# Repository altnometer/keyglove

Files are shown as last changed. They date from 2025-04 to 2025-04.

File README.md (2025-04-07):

# keyglove

This repository contains:
- Fusion API scripts which generate 3D model parts that can be used to
  assemble an ergonomic computer keyboard.
- STL files for printing a prototype of the keyboard.
  - Please be aware that the prototype version does not matches the
    latest script settings. You will need to wait a couple of months
    for the first tagged version which will match the scripts
    settings. From that point, you will be able to adjust the scripts
    and print out parts for your own preferences.

You can get a free hobbyist/learner license from Autodesk and try out
these scripts in Fusion platform for 3D CAD (Computer-Aided
Design).

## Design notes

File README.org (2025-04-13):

* Projects name: Customizable KeyGlove keyboard

This repository can help you build a personalized keyboard that
matches your hand for a close to perfect fit.

1. Use the provided scripts ([[./fingers.py]] and [[./thumb.py]]) to adjust
   the
   - location,
     + in horizontal and
     + vertical dimensions,
   - incline and
   - rotation
   of the keys to match exactly your finger placement.
2. Combine the parts in CAD (computer aided design) program.
3. Print out.
4. Build.
5. Try out.
6. Repeat until satisfied.

#+caption: keyglove_ergonomic_keyboard
#+ATTR_ORG: :width 800px
#+attr_html: :width 150px
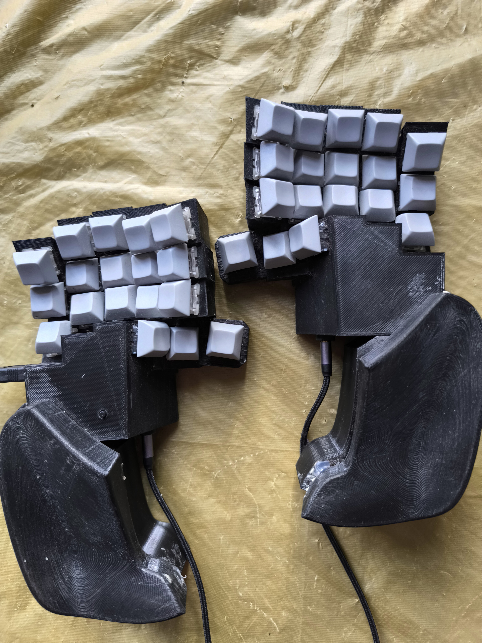
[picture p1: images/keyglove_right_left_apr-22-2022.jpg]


** [[Table of Contents]]

** [[Project Overview]]

** [[Features]]

** [[Parts List]]

** [[Build Process]]

** [[Wiring and Soldering]]

** [[QMK Firmware Setup]]

** [[Usage]]

** [[Customazation]]

** [[Contributing]]

** [[License]]

** [[Acknowledgments]]

* Project Overview

From play dough concept:
#+caption: keyglove_playdough_concept
#+ATTR_ORG: :width 800px
#+attr_html: :width 150px
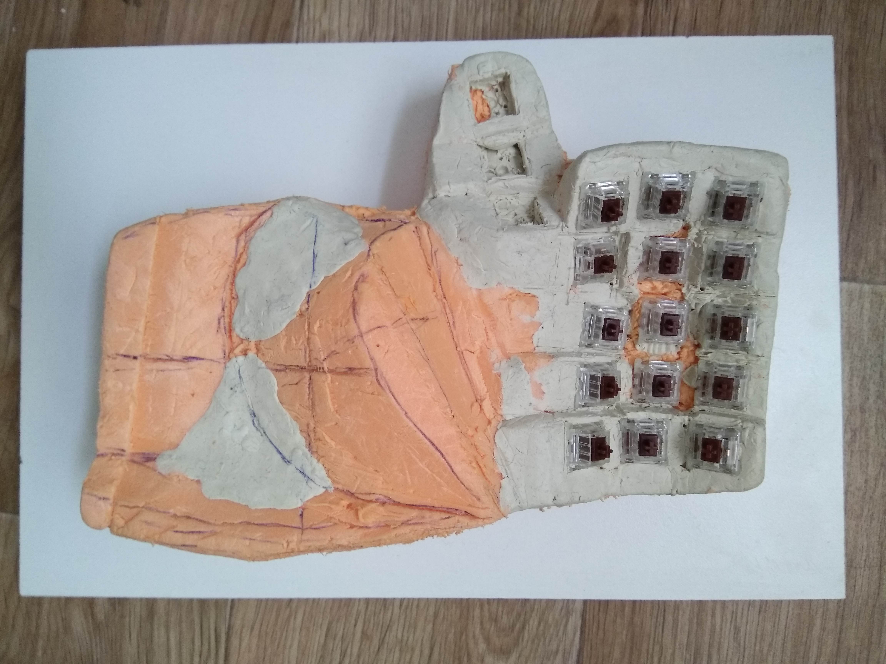
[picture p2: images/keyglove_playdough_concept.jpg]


Through countless trials:
#+caption: keyglove_3d_print_model
#+ATTR_ORG: :width 800px
#+attr_html: :width 150px
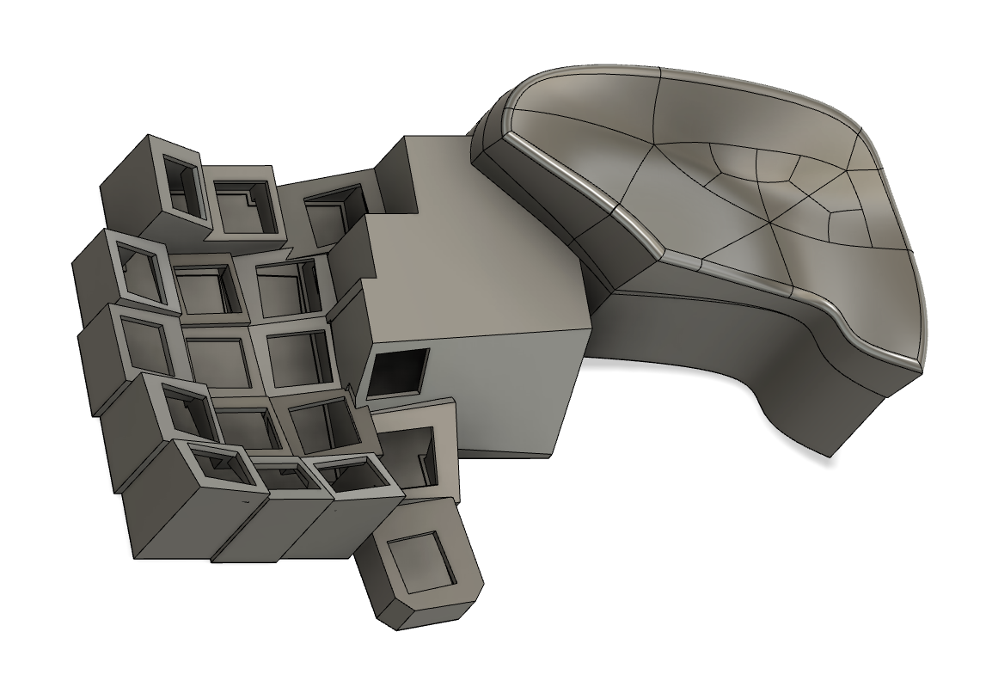
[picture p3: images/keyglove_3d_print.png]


Close to a perfect fit:
#+caption: keyglove_ergonomic_keyboard
#+ATTR_ORG: :width 800px
#+attr_html: :width 150px
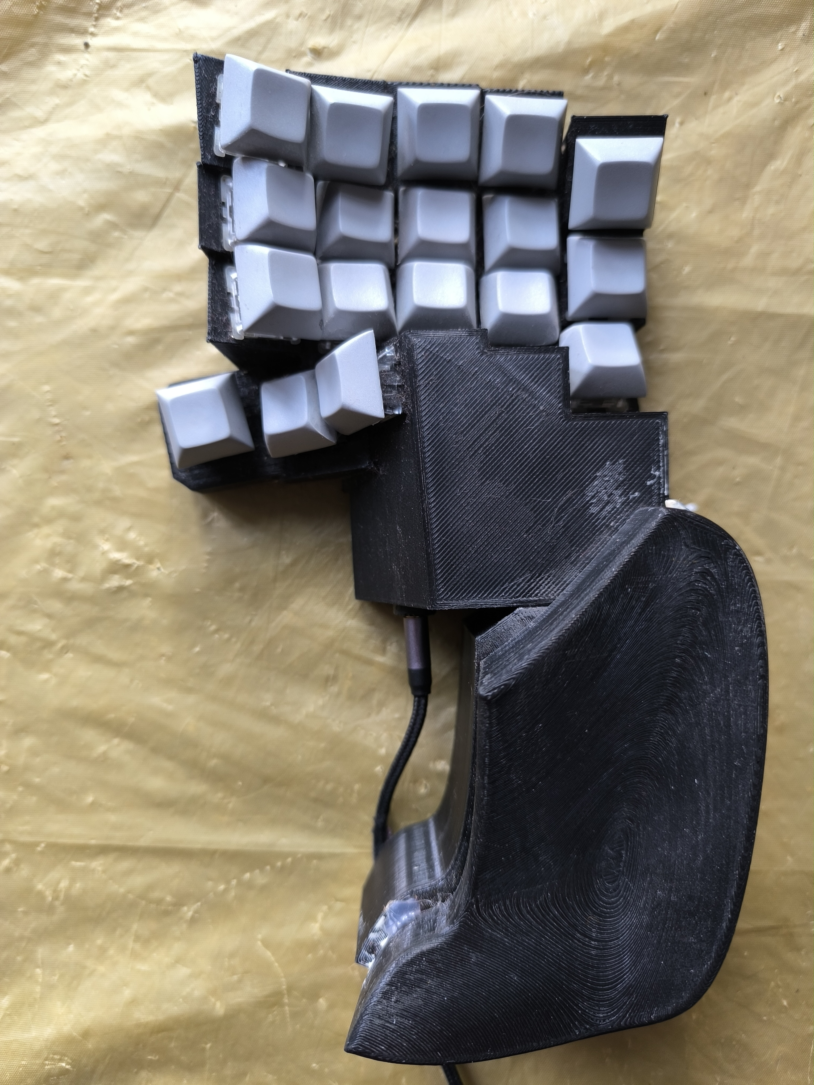
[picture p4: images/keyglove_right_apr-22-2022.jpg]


TODO:
A brief description of your keyboard:
- what makes it unique (e.g., ergonomic, wireless, THIRD-printed case).
- Target audience (e.g., writers, coders, gamers, etc).
- Tools required (soldering tools, THIRD printer, etc).

* Features

** Layout

1. The location, incline and rotation of every key is found through
   countless trials to match the optimal placement of fingers of my
   hand. No lifting of the palm is necessary to input the whole range
   of characters.
2. (TODO: link) The [[QMK Firmware Setup][QMK firmware]] is used
   - to enable the layout with all modifier keys (i.e., =Ctrl=, =Shift=
     and =Meta=) on the home row.
   - to enable activating the layout layers for
     + numbers and
     + symbols

** Switches

Your preferred switches, e.g.,
- Cherry MX Blue,
- Gateron Brown,
- etc

** Connectivity

USB

** Case Material

3D-printed,
Tried only:
- PEG type plastics for durability and strength

* Parts List

There are 36 keys in this keyboard. Hence, for things like
- key switches
- keycaps
- diods
- etc
You will need at least 36 pieces of each. Make sure you have some
spare ones as well.

** 3D-Printed Case

Start by printing the cases from provided STL files. If you wish to
adjust the key positions, use the scripts (TODO: link) to create
modified cases (for right and left hands).

** Microcontroller

Quantity: 2

** Key Switches

1. key switches, e.g.,  Gateron Browns, Plus a few spare ones
2. Different keys for finger keys (e.g., Gateron Brown) and thumb keys
   (used mainly for layer switching), e.g., Kailh Silver, linear, with
   shorter activation levels, with added key rings to minimize time,
   distance traveled for faster responses.

** Keycaps

DSA key caps. Please, be advise, you will need to grind off some of
the keycaps to fit them. Hence, make sure you have some spare keycaps.

 [[https://aliexpress.ru/item/32850729893.html?spm=a2g2w.orderdetail.0.0.12124aa6Vw1juY&sku_id=65628321594][AliExpress DSA keycaps]]

** Diodes

quality diodes.

** 4 pole 3.5mm trrs audio jack socket

Make sure it is of trrs type (not yrs).

For example:
[[./images/trrs_audio_jack_socket.jpg_220x220.webp]]

** other parts

TODO: make their own sections

4 pole 3.5mm trrs audio jack cable

USB type A (largest USB connectors for durability).
- socket
- cable

** soldering wire

* Build Process

** Prepare the Case

Print the case from the =3d_prints= directory. Ensure that surfaces for
the key switches are even and smooth. Sand and finish to your liking.

** Assemble Components

- Glue the switches section and hand rest section together.
- find the best location for the palm rest section (location for the right and left
  hands may differ).

Mount switches:
- ensure consistent orientation
Mount other components
- USB socket
- trrs socket
  + connect right and left hand parts
  + !!! Never disconnect right and left parts while the keyboard is
    powered.
- TODO: complete list

There is not specific holder for the micro controller.

** Solder Switches and Diodes

*** Wiring and Soldering

TODO: add images of wiring

Maybe (not likely) wiring schematic on or Fritzing diagram.

**** switches and diodes

**** 4 pole 3.5mm trrs audio jack socket

Insert, then solder.

!!! Pull up resistor (include resistor specs).

**** USB type A

Insert, then solder.

There is a rudimentary holder for the socket. You may need to cut the
place holder to size. Just use the soldering iron to melt it to size.
Glue for greater strength.

* QMK Firmware Setup

Please, see the [[https://github.com/altnometer/qmk_firmware][my QMK firmwaer repository]] for the configuration
examples.

In this repository, my settings for this keyboard are located in:
- =./qmk_firmware/keyboards/handwired/altnometer/= directory

** Example of BEAKL 10 layout

As an example, consider the settings for the BEAKL 10 layout located
in the file:
- =./qmk_firmware/keyboards/handwired/altnometer/keymaps/beakl/keymap.c=

Here is the relevant extract from the file:
#+begin_src C
// ./qmk_firmware/keyboards/handwired/altnometer/keymaps/beakl/keymap.c

// ...

/* _BEAKL (beakl10)
 * ,----------------------------------.             ,----------------------------------.
 * |  Q   |  H   |  O   |  U   |  X   |             |   G  |   D  |   N  |   M  |   V  |
 * |------+------+------+------+------+             +------+------+------+------+------|
 * |  Y   |  I   |  E   |  A   | .  # |             |   C  |   S  |   R  |   T  |   W  |
 * |------+------+------+------+------+             +------+------+------+------+------|
 * |  J   | /  ? | '  ` | ,  ! |  Z   |             |   B  |   P  |   L  |   F  |   K  |
 * `------+------+------+------+------+             +------+------+------+------+------'
 *               | Esc  | Spc  | BkSp |             |  Tab | Entr |  Esc |
 *               `--------------------'             `--------------------'
 *                   ^      ^      ^                    ^      ^      ^
 *                  I3     Symb   Nav                 Shft    Num    Shft
 */
 [_BEAKL] = LAYOUT(
  KC_Q   , KC_H   , KC_O   , KC_U   , KC_X   ,                   KC_G   , KC_D   , KC_N   , KC_M   , KC_V   ,
  KC_Y   , MALT_I , MSFT_E , MCTL_A , MY_DOT ,                   KC_C   , MCTL_S , MSFT_R , MALT_T , KC_W,
  KC_J   , KC_SLSH, MY_QUOT, MY_MINS, KC_Z   ,                   KC_B   , KC_P   , KC_L   , KC_F   , KC_K   ,
                    MGUI_BS, L_SYMSP, L_NAVES,                   L_FLRME, L_NUMEN, MY_ALTF
                    /* MGUI_BS, L_SYMSP, L_NAVES,                   L_FLRME, L_NUMEN, KC_TAB */
                    /* MGUI_BS, L_SYMSP, L_NAVES,                   L_FLRME, L_NUMEN, TH(0) */
),

// ...

#+end_src

** Firmware settings relevant to wiring

The settings specific to wiring this keyboard are located in:
- =./qmk_firmware/keyboards/handwired/altnometer/config.h=

Some examples of relevant settings are:

#+begin_src C
// ./qmk_firmware/keyboards/handwired/altnometer/config.h

/* key matrix size */
// rows are doubled-up
#define MATRIX_ROWS 8
#define MATRIX_COLS 5
#+end_src

#+begin_src C
// ./qmk_firmware/keyboards/handwired/altnometer/config.h
// these are the pins on the microcontroler
// that you solder the rows and columns to
#define MATRIX_ROW_PINS { B1, B3, B2, B6 }
#define MATRIX_COL_PINS { B5, B4, E6, D7, C6 }
#define UNUSED_PINS
#+end_src

** Flashing the Micro controller:

Please, follow the [[https://qmk.fm/]] instructions.

** Customize keymaps using QMK

* Usage

Ensure your elbow are the same level as the wrists.

- Connect via USB or Bluetooth

* Customazation

- Print out,
- assemble switches and caps,
- find your own location for the palm rest.
- try out:
  + keep checking the fit for a weak or two (it is better to let your
    hand adjust a little rather than adjusting the key locations for a
    new cycle)
- when made your mind, either
  + solder the keys and complete your fully functional keyboard
  OR
  + adjust the settings in the scripts (TODO: link) to modify the key
    locations.

- Modify the case design in =cad_models/=

* Contributing

The repository is not under any active maintenance. It is simple
enough. No need for complexity. When you find your best fit, give it a
year or two to drive test. You may just enjoy easier, more productive
interacting with a computer after.

Consider migrating the scripts to open source software (solutions).

1. Fork the repository.
2. Submit a PR with clear changes.

* License

This project is licensed under the MIT License

* Acknowledgments

Inspired by [[https://qmk.fm/][QMK community]]

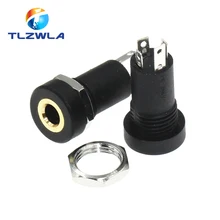
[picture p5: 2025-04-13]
images/trrs_audio_jack_socket.jpg_220x220.webp

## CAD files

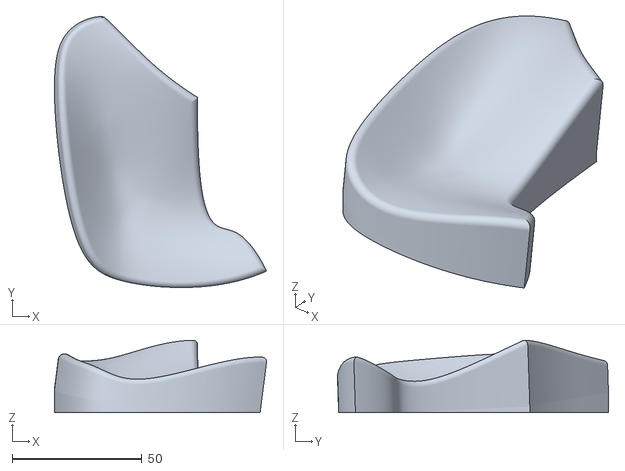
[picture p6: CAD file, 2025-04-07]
3D_prints/apr-22-2022/left/left-apr-22-2022-palm-rest.stl
81.6 x 104.3 x 27.9

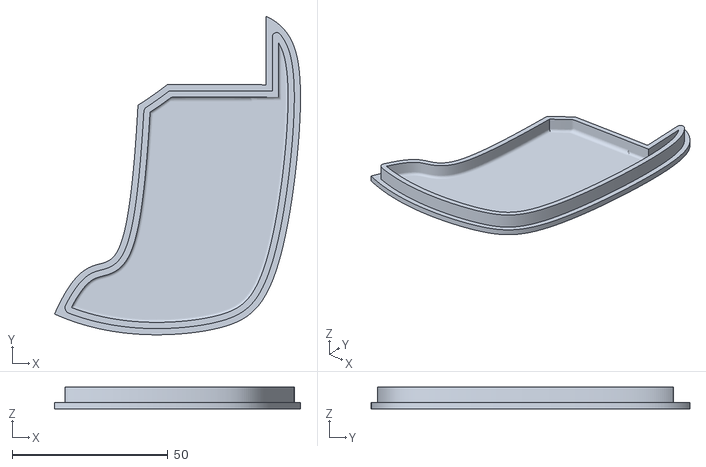
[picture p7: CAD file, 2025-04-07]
3D_prints/apr-22-2022/right/right-apr-22-2022-palm-base-bottom.stl
79.1 x 102.4 x 7.00

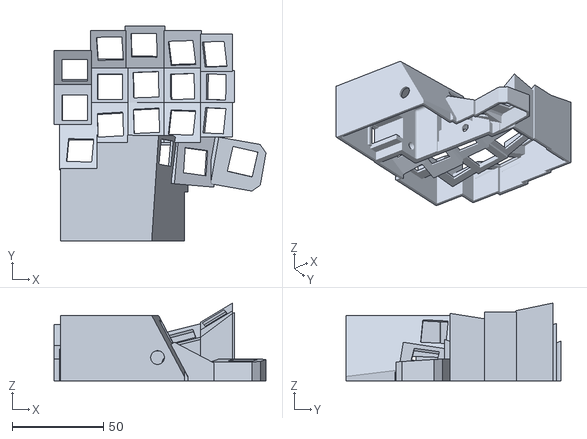
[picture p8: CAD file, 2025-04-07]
3D_prints/apr-22-2022/left/left-apr-22-2022-fingers-thumb.stl
116.3 x 118.1 x 42.8

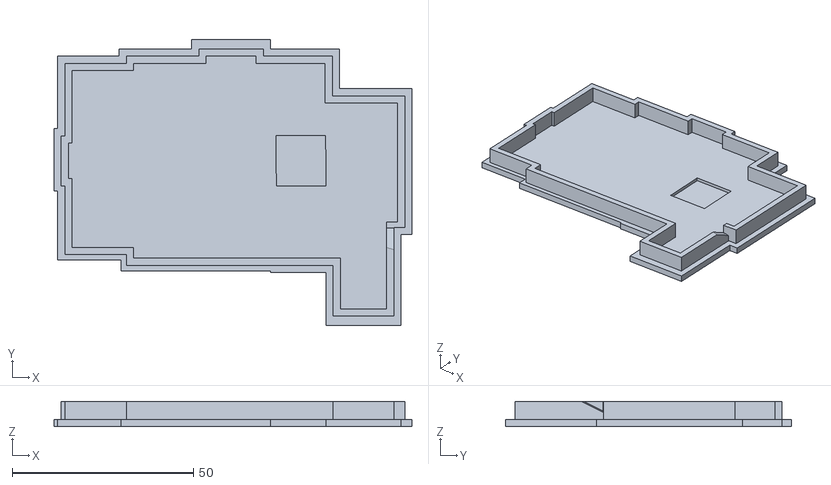
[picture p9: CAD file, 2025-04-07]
3D_prints/apr-22-2022/right/right-apr-22-2022-fingers-bottom.stl
98.8 x 78.8 x 7.00

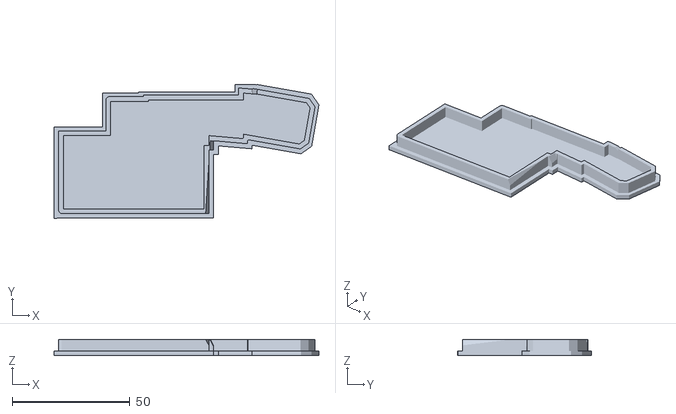
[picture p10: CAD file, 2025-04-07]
3D_prints/apr-22-2022/left/left-apr-22-2022-thumb-bottom.stl
112.7 x 56.9 x 7.00

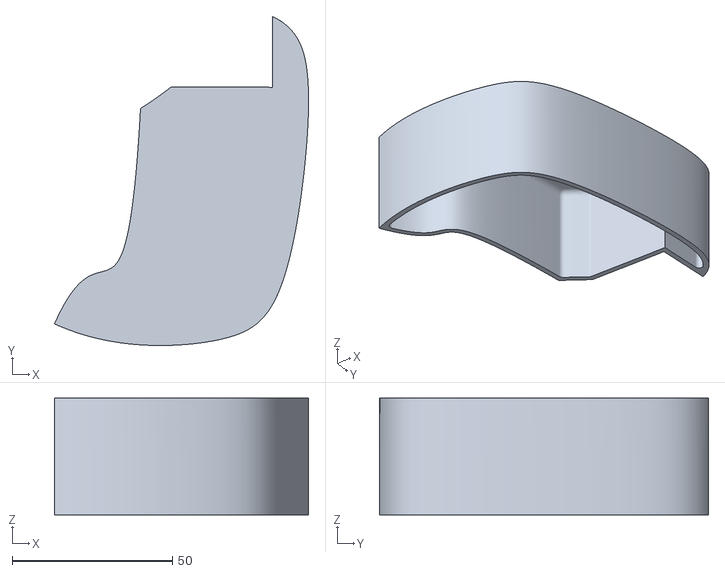
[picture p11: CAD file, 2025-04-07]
3D_prints/apr-22-2022/right/right-apr-22-2022-palm-base.stl
79.3 x 102.7 x 36.5

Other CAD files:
3D_prints/apr-22-2022/right/right-apr-22-2022-palm-rest.stl
3D_prints/apr-22-2022/left/left-apr-22-2022-fingers-bottom.stl
3D_prints/apr-22-2022/left/left-apr-22-2022-palm-base.stl
3D_prints/apr-22-2022/right/right-apr-22-2022-thumb-bottom.stl
3D_prints/apr-22-2022/left/left-apr-22-2022-palm-base-bottom.stl
3D_prints/apr-22-2022/right/right-apr-22-2022-fingers-thumb.stl

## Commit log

2019-03-30 Drafted untested cut_off_at_inner_top_from_base
    The fn is for thumb section.
    It is supposed to cut of the base segment bit that sticks out
    over its top surface.
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2019-03-30 Increased the length of top finger segments
    Added 2 mm to all index [n][0] segments.
    Adjusted switch center values accordingly (by -1 mm),
    except the mdl0 which needed to be moved away from the center.
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2019-03-30 Fixed incorrect change of indx2 switch ycoord
    it was meant to be xcoord
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2019-03-30 fixed incorrect mdl2 switch ycoord change
    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
2019-06-18 thumb: middle: made wider by 4 mm
    By increasing the middle width, we hope to reduce the inner width.
    This is an attempt to enable a steeper surface slope for the inner segment.
    Otherwise, the surface might be too long to handle correctly.
2019-06-18 thumb/middle: moved middle0_switch_center left by 2mm
    As we increased the middle section width by 4mm, we need to move the
    middle0_switch_center to the left by 2mm if we want the switch center
    to remain in the original position.
2019-06-18 thumb/middle: added middle0_adjust_xcoord_for_width_change
    As we increased the segment width by 4mm, we need to move
    the segment to the right by 2mm, because we want all of the 4mm
    on the right side.
2019-06-18 thumb/inner: reduced inner_segment_width by 4mm
    Adjusted inner0_xcoord to keep the segment center in the same place.
    Hopefully, the width increase in the middle section will cover the gap
    between the inner and middle sections.
2019-06-18 thumb/inner: inner0_hight is set to absolute min
    The 26mm is the absolute min that is possible to set for this
    segment hight. Any smaller value breaks the current script.
    Consider changing THUMB_SECTION_HIGHT and the settings that rely on it
    if you need to set this segment hight to a lower value.
2019-06-19 thumb/inner: increased surface slope
    Increased inner0_surf_mdl from 19mm to 30mm, inner0_surf_high from 24mm
    to 34mm.
    Changed the slope direction: changed the coords of low, mdl and high
    coord.
2019-06-19 thumb/inner: moved inner0_switch_center right
    With the segments current steep slope, moving the switch center to the
    right moves it up.
2019-06-19 thumb: modified check if inner0_surf_high sticks out
    If the difference between inner0_surf_high and base0_hight is
    under 1mm, fusion360 raises 'tool does not intersect the body' error.
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2019-06-19 ring0: moved switch away from center by 0.5mm
    Because it touched middle1 switch.
2019-06-19 ring0: moved switch right by 0.25mm
    Because it touches middle0 keycap.
    middle0 should be moved to the left by 0.25mm as well.
2019-06-19 mdl0: moved switch left by 0.25mm
    Because it touched ring0 key cap.
2019-06-19 Raised mdl0_hight by 1mm
    It felt that it was too low.
2019-06-19 pinky0: moved closer to homerow key
    The hight is raised by 1.4mm and the switch is moved toward the
    center by 2mm. With the steep surface slope (about 45 degrees) it
    lowers the key as well. So, by raising the segment hight and lowering
    the switch (while moving toward the homerow key) we should keep the
    switch at the same height while bringing it closer to the homerow pinky
    key.
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2019-08-14 base0_hight: raised by 5mm
    Raised because the inner section would stick over the
    top surface of base section.
2019-09-07 fingers: corrected linting "overindent" error
2019-09-07 pinky2_length: increased by 3mm
    The intent is to move the switch away from the center as it touches the
    pinky1 switch. As there is no room left to move the switch_center safely (the
    switch would be pressed against the side wall), we have to
    increase the segment length by 3mm.
    This should move the switch_center by 1.5mm away from the
    center.
    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
2021-02-15 thumb/inner: rename, change value for xcoord setting
    inner0_adjust_xcoord_for_rotation is renamed for
    inner0_adjust_xcoord_segment_position. Its value is changed from 2mm
    to -4mm.
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2021-02-18 fingers: fix typo
2021-02-18 fingers: change misleading constant name
    Change indxpls_row_width to indxpls_width, as it is not
    a row, but rather a column.
2021-03-18 indxpls2: reduce length by from 23 to 19
    Adjust switch center coord and indxpls2_surf_high to
    keep the switch center and the surface incline same as they were.
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2021-03-22 fingers: put mdl settings in front of others
    Because redefined xcoord for other segments may rely on the width of
    mdl segments.
2021-03-22 mdl0: increase width to mdl_row_width + 1
    This is to compensate the reduction in width for
    ring0_width (see previous commits).
    mdl0_switch_center has to be modified to keep the switch in its
    original location.
2021-03-22 ring0: increase width to ring_row_width - 1
    ring0_switch_center has to be modified to keep the switch in its
    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
2021-03-22 pinky0: reduce length from 24 to 16
    Adjust pinky0_switch_center to keep the switch in its original
    location.
    Adjust pinky0_surf_mdl and pinky0_surf_high to keep the original
    switch surface incline.
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2021-03-23 pinky0: increase length from 16 to 18
    At previous length, the switch hole would cut into the side. Modified
    switch center and incline values to keep the switch in the original
    position. Modify pinky_ycoord_adjustment to keep the segments in there
    original locations.
2021-03-23 fingers: fix values for width from incorrect cm to mm
2021-03-23 fingers: modify segment location calculation
    An adjacent segments location is used for calculation.
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2021-03-24 thumb/inner0,middle0: revert changes to *_ycoord_adjust
    Change inner0_ycoord_adjust and middle0_ycoord_adjust to their
    original values.
    Apparently, the changes that this commit reverts were
    motivated from the layout of finger and thumb section that had
    erroneously set the finger section 4 mm further from the thumb section
    than its correct position.
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2021-04-27 fingers: adjust *_switch_center coordinates
    After reducing length and width of segments in previous commits, some
    switch locations became misaligned. This commit adjust switch center
    coordinates to realign the switch holes with previous locations.
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2025-04-07 add STL files for 3D printing the keyboard
    [left-apr-22-2022-fingers-bottom.stl, left-apr-22-2022-fingers-thumb.stl, left-apr-22-2022-palm-base-bottom.stl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]
